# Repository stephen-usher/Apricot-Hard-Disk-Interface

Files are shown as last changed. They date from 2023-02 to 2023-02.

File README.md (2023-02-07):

# Apricot-Hard-Disk-Interface
 This is a board for the ACT Apricot series of computers providing virtual hard disks held on a FAT format microSD card.

 The core of this is a Raspberry Pi Pico which pretends to be most of the circuity on the original "Winchester Card", i.e. the WD1010-05 MFM hard disk controller chip, the 8K transfer static RAM and the  control latch. The main address translation is done via the two GALs and data/addresses and voltage levels are managed via the 74LS and 74AHCT chips controlled by the GALs.

 The board can be built in two forms. The first is fully populated and is a stand-alone unit which just plugs into the Apricot expansion bus connector. The second form is as a daughter board to my RAM  expansion card (which needs one bodge wire added to bring the ALE signal to the expansion connector) in which case it only requires the two 74AHCT chips and one GAL as all the other functionality is  provided by the RAM card.

 The source and binaries for the GAL code can be found in the GAL sub-directory.

 The Raspberry Pi Pico's software is written in C using the Pico SDK. I used the version which runs on a Raspberry Pi 4 to develop this. One core is used for the host interface and the other for the less  time critical parts such as emulating the WD1010-05 commands and talking to the microSD card.

 The microSD card interface I used was easily found on Amazon and targetted at the Arduino, hence why it is a 5V model. It's an "AZ-Delivery SPI Reader Micro". Others will probably work but the pin-outs may  be different.

 The PCB was designed using KiCAD 6.

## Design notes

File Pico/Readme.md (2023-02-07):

# The Raspberry Pi Pico code.
 The three directories here hold the source and binary files of the firmware for the Pico along with a dirctory with some sample hard disk images.

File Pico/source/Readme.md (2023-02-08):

# Raspberry Pi Pico firmware source.
 This source includes a copy of the ["no-OS-FatFS-SD-SPI-RPi-Pico" code by "carlk"](https://github.com/carlk3/no-OS-FatFS-SD-SPI-RPi-Pico), so as to access the micoSD card via SPI. This in turn has a copy of  [ChaN's FatFs - Generic FAT Filesystem Module.](http://elm-chan.org/fsw/ff/00index_e.html).

 The architecture is quite simple. The system first sets up the pins on the Pico, initialises the SD card interface, reads the config file and sets up the configuration for the virtual hard drives. It then  runs the host interface code on core 1 whilst core 0 waits for WD1010-05 commands and actions them.

 The buffer and many variables are shareed between the two cores, the variables being defined as volatile so that the compiler knows not to optimise accesses away or cache the values. This acts as the inter  core communication.

 Currently the only outstanding issue is that format.exe and the Activity Disk Tools format both hang when doing the low-level format. Actually, the programs both do a seek command, check the status register once after it's completed and then just sit there. There's no further interaction from the host. I've tried all potentially valid status register values and it makes no difference.

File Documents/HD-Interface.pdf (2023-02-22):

# !Electronic Svstem

1. Outline Of Controller.
2. Integrated Circuit Catalogue
3. Mnemonics

### 1. Outline of Controller

Introduction
The Winchester disk drive controller is a single board expansion card which fits into either one of the system expansion slots and connected to the disk drive by a ribbon cable.
The board acts as the interface between the processing system and the Winchester disk drive.

Description
The controller is broken into seven parts; the WD 1010-05, Data seperator, write precompesation, addressing, RAM buffer control port and finally a data bus.

Winchester Disk Controller (WD1010-05)
The Winchester disk interface consists of a WD 1 0 1 0-05 and associated buffers.
The interface provides all the control functions necessary for formatting and transferring data to and from the winchester disk.

Winchester 9

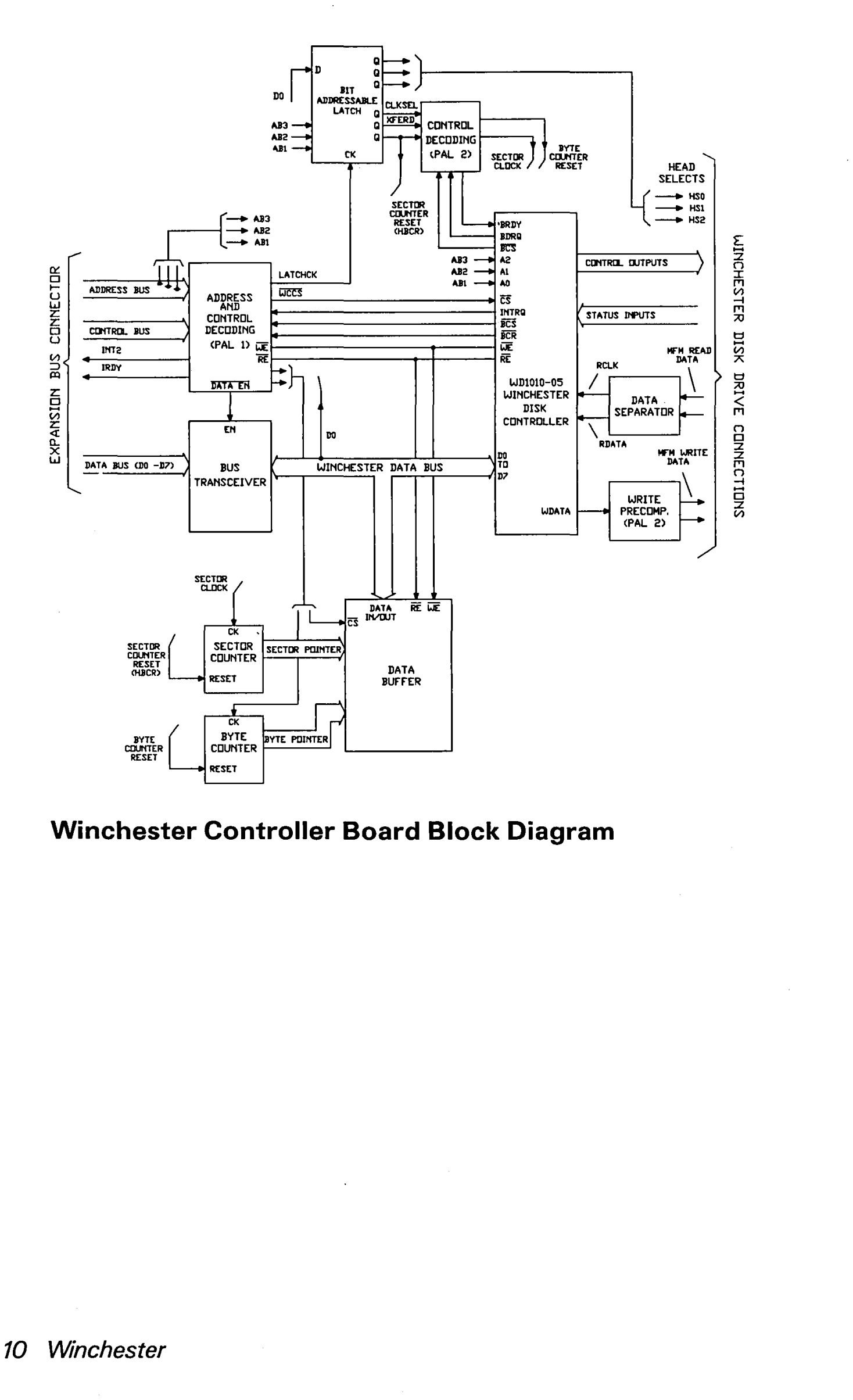
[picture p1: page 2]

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
'" ::::>

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
J:j_A113 _A112
_AlII

ADIlRt:SS BUS

ClJiTR!I.. BUS

ItfT2

DATA BUS (DO -D7)

SECTOR
CIlUIiTER
RESET
CHBCR)

BVTE CDUlfTER
RESET

ADDRESS AND

CONTROL
DECODING

EN

BUS
TRANSCEIVER

DO

A113

BYTE ClUfTER
RESET | HEAD

RE

WDIOIO-OS
WINCHESTER
DISK
CONTROLLER
DO

WINCHESTER DATA BUS ,-.-,-----{ID7

WDATA

SELECTS

_IiSO
_1iS1
_HS2

Winchester Controller Board Block Diagram

### 10 Winchester

£
2
n
I
rTJ
'" ⁻⁻I

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
The WD 1010-05 is selected by WCCS from PAL 1 . Head select is controlled by the control port (IC8).
The controllers registers are selected by AB 1 - 3 from the Apricot.

Data Separator.
The DP8460 (lC2) data separator receives digital pulses from a differential line receiver which converts the data from balanced to TTL format. The data separators lock to the frequency of these input pulses and separates them into synchronized data and clock signals.

Write Precompensation
The Rodime R0350 does not require write precompensation although the controller is capable of producing early, normal and late data. Write data (WDATA) from the WD 1010-05 can be used to drive a delay line, (Not normally fitted). This generates two extra write data signals delayed by 1 Ons and 20ns. These data signals are then selected by PAL2 which is controlled by RWC/EARLY and LATE from the WD1010-05. The write data output of PAL2 is converted to balanced format by the differential line drive.

Addressing.
The PAL 1 is used to interface the address bus from the Apricot to the Winchester controller. It receives address lines AB4-AB8 which allows the controller to detect accesses to the WD1010-05.
The control port and the data port ABO qualifies the device selects and ALE is used to prevent glitches as the addresses change.
When the WD 1010-05 isolates the local bus to perform a data transfer the PAL 1 would produce NRAMCS from the appropriate address. PAL 1 is also enabled by BCS from the WD1010-05.
The WD 1010-05 interrupt request output (INTRQ) is bufferd by PAL 1 and output as NINT2 to the Apricot.
To meet the address setup times of the WD 10 10-05, the read enable signal is delayed by qualifying it with the data enable signal whenever the controller is addressed by the Apricot Ica also adds additional wait states by holding IRDY low until its Qc output goes high. This counter is clocked by the 5MHz clock (CLK5).

The expansion bus is buffered by tri-state drivers to avoid contention with other expansion cards.

Control Port
The control port (IC6) is an 8 bit addressable latch enabled by the signallatch-CK from PAL 1.
The signals HSO-HS2 are used to select the winchester head. ClKSEl defines if the system processor or the WD 1 0 1 0-05 causes the sector pointer to be incremented.
XFERD is a handshaking protocol informing the
WD 1010-05 that data is available.
HBCR is used to reset both the sector pointer and the byte pointer to zero. It is controlled by the system processor.

Data Bus
The local data bus is isolated from the expansion bus by IC5 an octal bus transceiver. Its"direction is controlled by NIORC from the Apricot and enabled by NDATAEN from PAL 1.

Static Ram.
This 8K x 8 or 2K x 8 bit buffer acts as a temporary store for all data transfers. Data is written into the buffer from the Apricot and then access is passed to the WD 1010-05 which transferes the data to the winchester disk.
RAM chip select, read enable and write enable are controlled by PAL 1.
The RAM addresses are generated by counters which form the byte pointer( IC7 + IC 1 O} and sector pointer{lC8}.

The byte counter is incremented by the byte clock from
PAL 1 and goes high whenever RE or WE is active from either the CPU or WD10105.
The sector counter is clocked by sector ClK from PAl2. This is derived from either the Byte counter reaching its
maximum count or from the buffer data request of the WD1010-05.
The byte counter is reset by the signal BCR from IC4. This is generated by either the system {HBCR} or the WD 1 01 0-05 (NWBCR).
The sector counter is only reset by the system {HBCR}, this is to allow for a WD 1010-05 option to be implemented.

12 Winchester

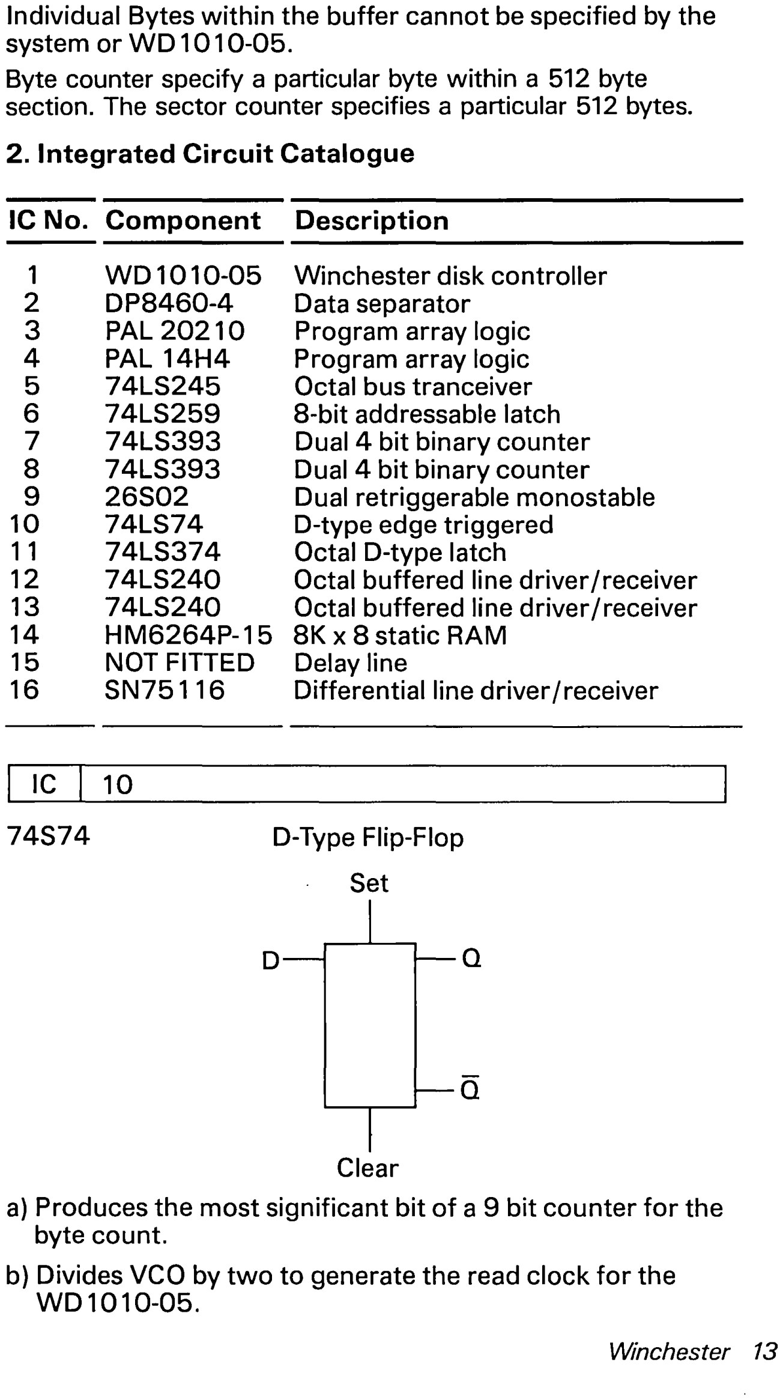
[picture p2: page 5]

Individual Bytes within the buffer cannot be specified by the system or WD 1 0 1 0-05.
Byte counter specify a particular byte within a 512 byte section. The sector counter specifies a particular 512 bytes.
2. Integrated Circuit Catalogue

IC No. Component Description

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
WD1010-05
DP8460-4
PAL 20210
PAL 14H4
74LS245
74LS259
74LS393
74LS393
26S02
74LS74
74LS374
74LS240
74LS240
HM6264P-15
NOT FITTED
SN75116

IC 10

Winchester disk controller Data separator
Program array logic
Program array logic
Octal bus tranceiver
8-bit addressable latch
Dual 4 bit binary counter
Dual 4 bit binary counter
Dual retriggerable monostable D-type edge triggered
Octal D-type latch
Octal buffered line driver/receiver Octal buffered line driver/receiver 8K x 8 static RAM
Delay line
Differential line driver/receiver
74S74 | D-Type Flip-Flop

Set

D | Q

0:

Clear
a) Produces the most significant bit of a 9 bit counter for the byte count.
b) Divides VCO by two to generate the read clock for the WD1010-05.

IC | 11
74LS374 | Octal D-Type Flip Flop.
D | Q

Clk----f

D/P Enable

Latches write data and precompensation outputs from the Write data and precompensation outputs from the Winchester controller. It also latches write clock and buffer data request.

I IC I 12, 13

74LS240 Octal Buffer Line Driver/Receiver
IC 12 Seven buffers are used to buffer controller signals to the Winchester disk drive. The remaining buffer is used as an input to a 4 bit binary counter for the sector clock.
IC 13. Buffers used to buffer Winchester controller signals from the Winchester disk drive.

I IC I 7,8

74LS393 | 4 Bit Binary Counter

IC 7 dual 4 bit counter used to produce 8 bits of a 9 bit byte counter.
IC8 One counter used for the sector counter and the second allows for the addition of extra wait states.

14 Winchester

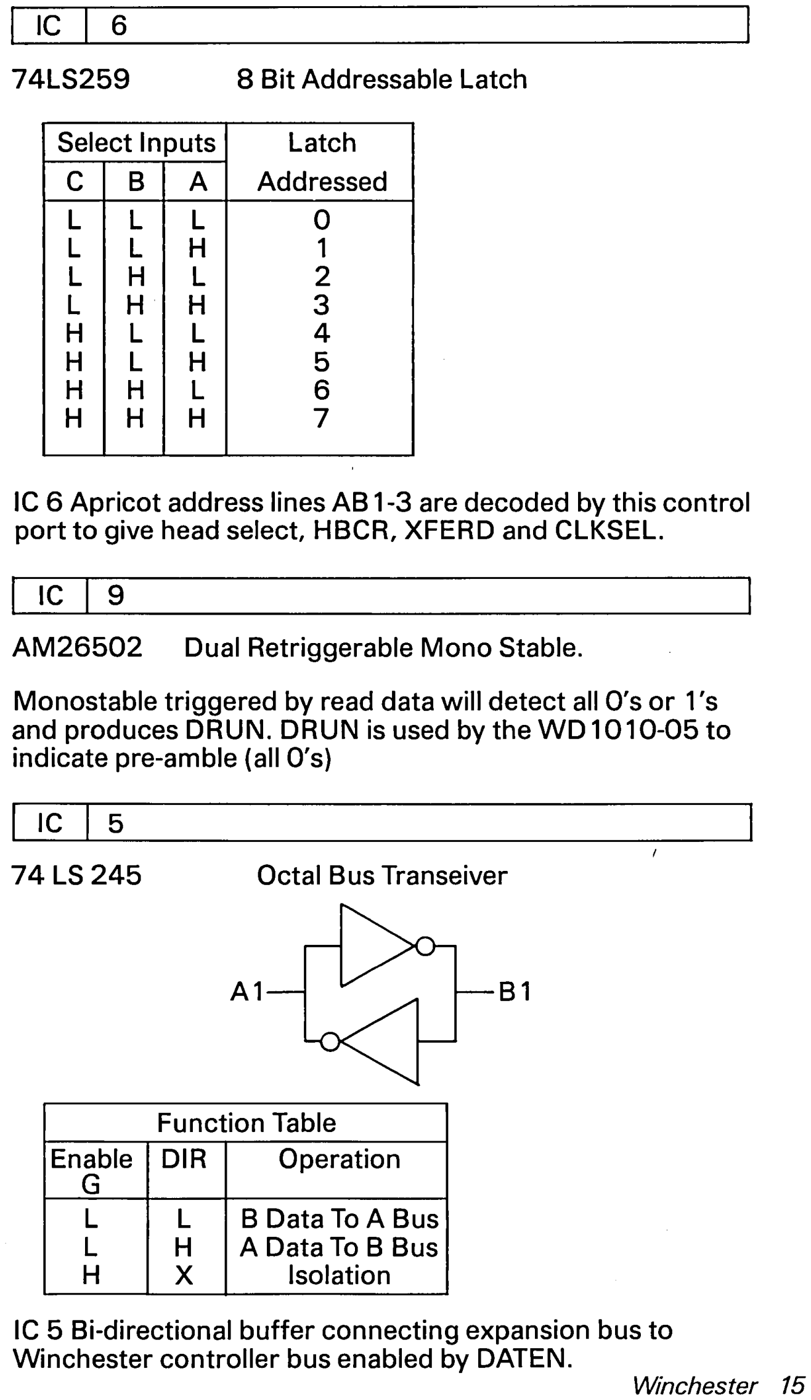
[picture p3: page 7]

Ie | 6
74LS259 | 8 Bit Addressable Latch
Select Inputs | Latch Addressed
C | B | A
L L L L H H H H | L L H H L L H H | L H L H L H L H | 0 1 2 3 4 5 6 7

IC 6 Apricot address lines AB 1-3 are decoded by this control port to give head select, HBCR, XFERD and CLKSEL.

I IC 19

AM26502 Dual Retriggerable Mono Stable.

Monostable triggered by read data will detect all O's or 1 's and produces DRUN. DRUN is used by the WD 1010-05 to indicate pre-amble (all O's)

# I IC I 5

74 LS 245 | Octal Bus Transeiver
A1 | B1

Function Table
Enable G | DIR | Operation
L L H | L H X | B Data To A Bus A Data To B Bus Isolation

IC 5 Bi-directional buffer connecting expansion bus to Winchester controller bus enabled by DATEN.

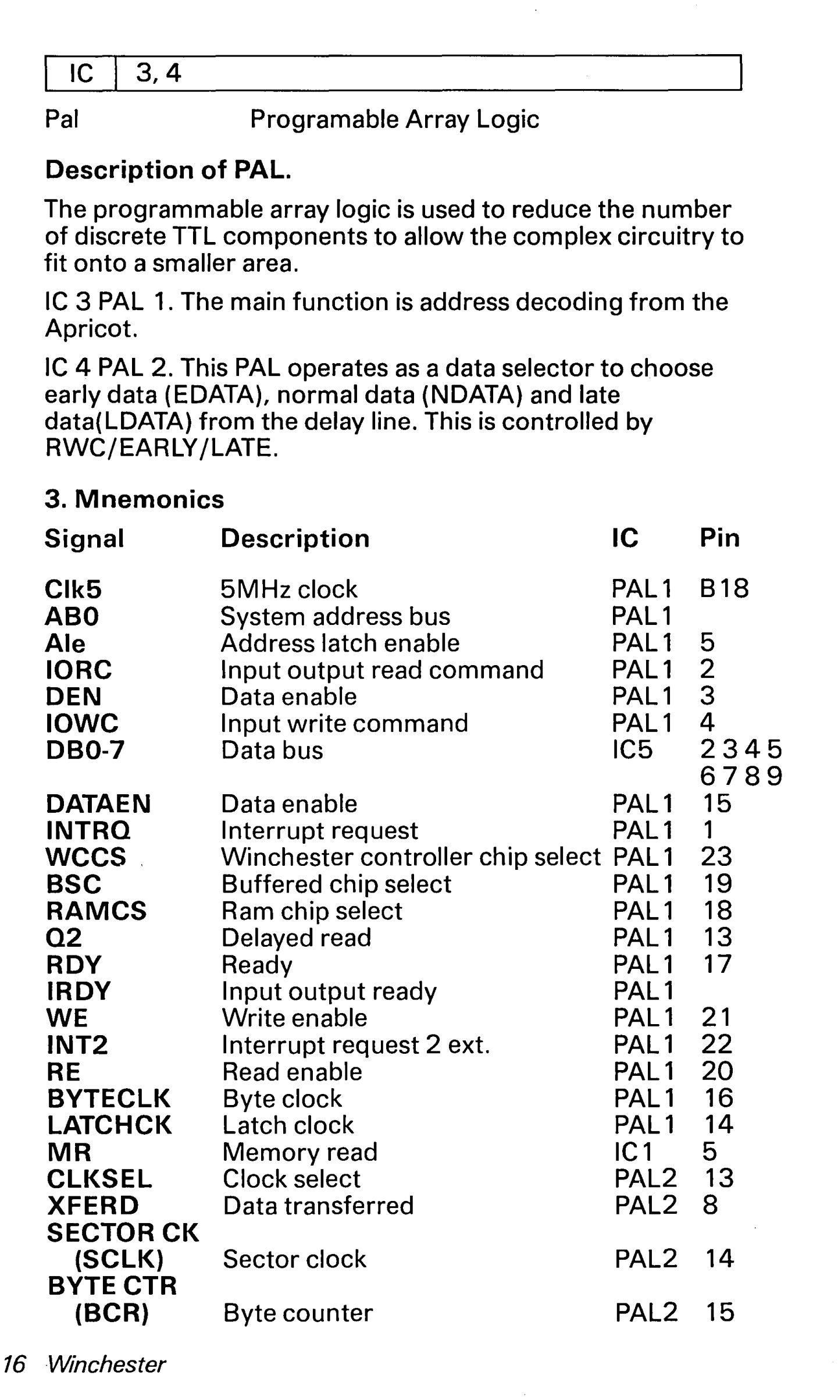
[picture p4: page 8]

16

IC | 3,4
Pal | Programable Array Logic

Description of PAL.
The programmable array logic is used to reduce the number of discrete TTL components to allow the complex circuitry to fit onto a smaller area.
IC 3 PAL 1. The main function is address decoding from the Apricot.
IC 4 PAL 2. This PAL operates as a data selector to choose early data (EDATA), normal data (NDATA) and late
data( LDATA) from the delay line. This is controlled by RWC/EARLY /LATE.
3. Mnemonics
Signal | Description | IC
Clk5 | 5MHz clock | PAL1
ABO | System address bus | PAL 1
Ale | Address latch enable | PAL1
IORC | Input output read command | PAL1
DEN | Data enable | PAL1
IOWC | Input write command | PAL 1
DBO-7 | Data bus | IC5
DATAEN | Data enable | PAL1
INTRO | Interrupt request | PAL 1
WCCS. | Winchester controller chip select PAL 1
BSC | Buffered chip select | PAL1
RAMCS | Ram chip select | PAL1
02 | Delayed read | PAL1
RDY | Ready | PAL1
IRDY | Input output ready | PAL1
WE | Write enable | PAL 1
INT2 | Interrupt request 2 ext. | PAL 1
RE | Read enable | PAL1
BYTECLK | Byte clock | PAL 1
LATCHCK | Latch clock | PAL1
MR | Memory read | le1
CLKSEL | Clock select | PAL2
XFERD | Data transferred | PAL2
SECTOR CK
(SCLK) | Sector clock | PAL2
BYTE CTR
(BCR) | Byte counter | PAL2

Winchester

Pin

B18

5
2
3
4
2345
6789
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
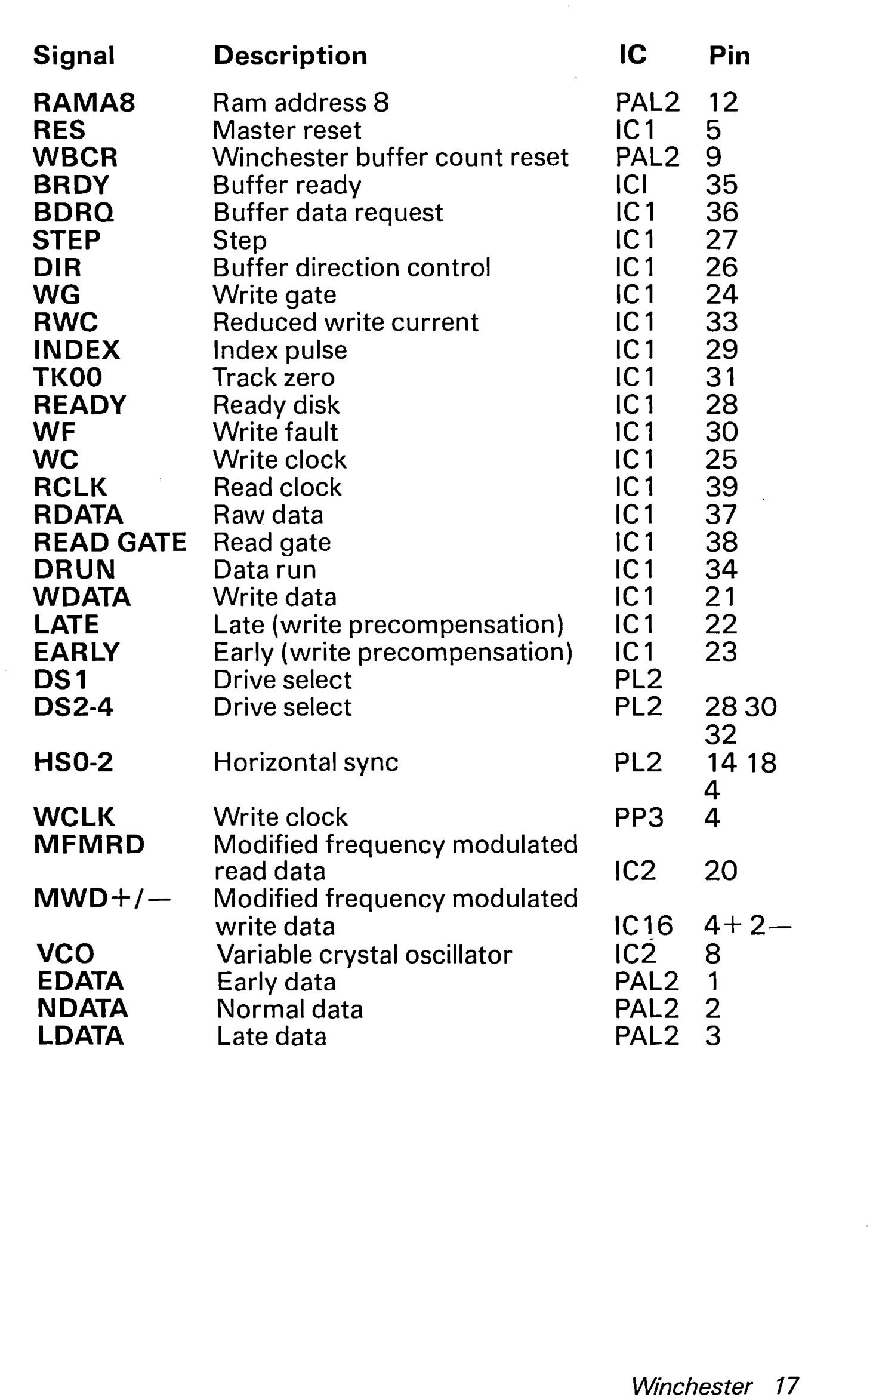
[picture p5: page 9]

Signal | Description | IC | Pin
RAMA8 | Ram address 8 | PAL2 12
RES | Master reset | IC 1 | 5
WBCR | Winchester buffer count reset | PAL2 9
BRDY | Buffer ready | ICI | 35
BDRQ | Buffer data request | IC 1 | 36
STEP | Step | IC1 | 27
DIR | Buffer direction control | IC1 | 26
WG | Write gate | IC1 | 24
RWC | Reduced write current | IC1 | 33
INDEX | Index pulse | IC1 | 29
TKOO | Track zero | IC1 | 31
READY | Ready disk | IC1 | 28
WF | Write fault | IC1 | 30
WC | Write clock | IC1 | 25
RCLK | Read clock | IC1 | 39
RDATA | Raw data | IC1 | 37
READ GATE Read gate | IC1 | 38
DRUN | Data run | IC1 | 34
WDATA | Write data | IC 1 | 21
LATE | Late (write precompensation) | IC1 | 22
EARLY | Early (write precompensation) | IC 1 | 23
DS1 | Drive select | PL2
DS2-4 | Drive select | PL2 | 2830
| | | 32
HSO-2 | Horizontal sync | PL2 | 14 18
| | | 4
WCLK | Write clock | PP3 | 4
MFMRD | Modified frequency modulated
| read data | IC2 | 20
MWD+/- | Modified frequency modulated
| write data | IC16 | 4+2-
VCO | Variable crystal oscillator | IC2 | 8
EDATA | Early data | PAL2 1
NDATA | Normal data | PAL2 2
LDATA | Late data | PAL2 3

# Parts list

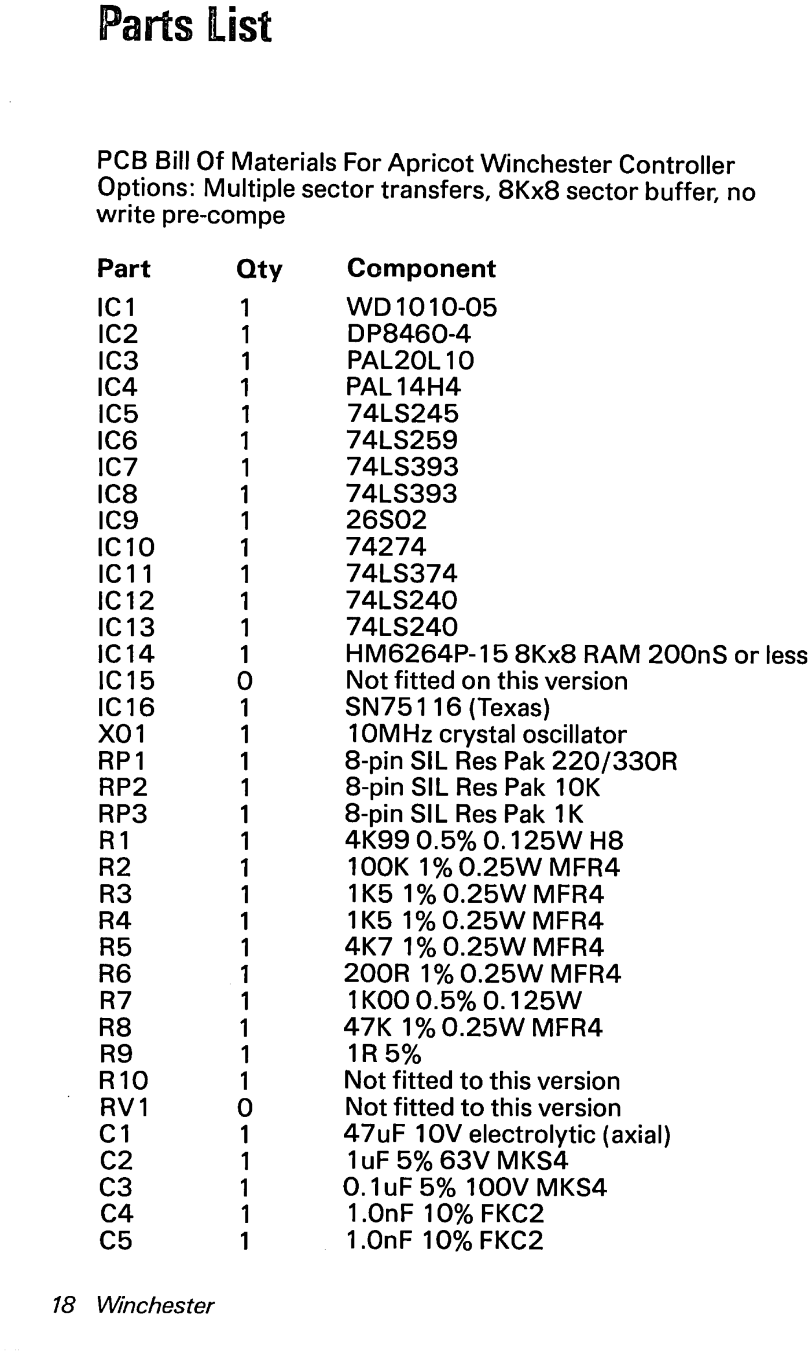
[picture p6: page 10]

PCB Bill Of Materials For Apricot Winchester Controller Options: Multiple sector transfers, 8Kx8 sector buffer, no write pre-compe

Part
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
IC10
IC 11
IC12
IC13
IC14
IC15
IC16
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
18 Winchester

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
Component
WD1010-05
DP8460-4
PAL20L10
PAL 14H4
74LS245
74LS259
74LS393
74LS393
26S02
74274
74LS374
74LS240
74LS240
HM6264P-15 8Kx8 RAM 200nS or less Not fitted on this version
SN75116 (Texas)
10M Hz crystal oscillator
8-pin SIL Res Pak 220/330R 8-pin SIL Res Pak 10K
8-pin SIL Res Pak 1 K
4K99 0.5% O. 125W H8
100K 1 % 0.25W MFR4
1 K5 1 % 0.25W MFR4
1 K5 1 % 0.25W MFR4
4K7 1% 0.25W MFR4
200R 1 % 0.25W MFR4
1 KOO 0.5% O. 125W
47K 1 % 0.25W MFR4
1R5%
Not fitted to this version Not fitted to this version 47uF 10V electrolytic (axial) 1 uF 5% 63V MKS4
O. 1 uF 5% 100V MKS4
1.0nF 10% FKC2
1.0nF 10% FKC2

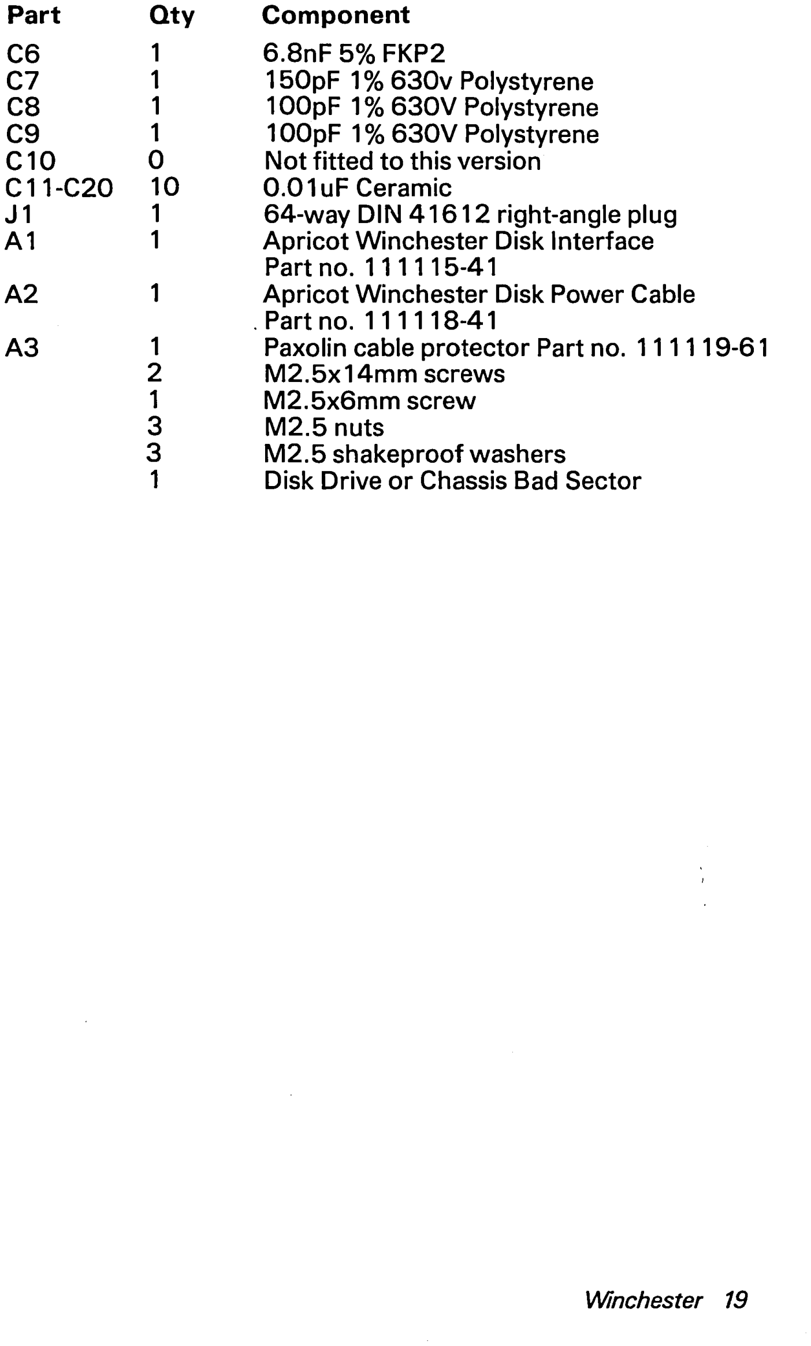
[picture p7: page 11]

Part | Qty
C6 | 1
C7 | 1
C8 | 1
C9 | 1
C10 | 0
C11-C20 | 10
J 1 | 1
A 1 | 1

A2

A3 | 1
2
| 1
3
| 3
| 1

Component
6.8nF 5% FKP2
150pF 1 % 630v Polystyrene 100pF 1 % 630V Polystyrene 100pF 1 % 630V Polystyrene
Not fitted to this version
0.01 uF Ceramic
64-way DIN 41612 right-angle plug Apricot Winchester Disk Interface Part no. 111115-41
Apricot Winchester Disk Power Cable
. Part no. 111118-41
Paxolin cable protector Part no. 111119-61 M2.5x 14mm screws
M2.5x6mm screw
M2.5 nuts
M2.5 shakeproof washers
Disk Drive or Chassis Bad Sector

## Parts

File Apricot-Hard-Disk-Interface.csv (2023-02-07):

Source: | Z:\Data\Kicad\Apricot-Hard-Disk-Interface\Apricot-Hard-Disk-Interface.kicad_sch
Date: | 18/12/2022 07:52:19
Tool: | Eeschema (6.0.9)
Generator: | C:\Program Files\KiCad\6.0\bin\scripting\plugins/bom_csv_grouped_by_value_with_fp.py
Component Count: | 21
Ref | Qnty | Value | Cmp name | Footprint | Description | Vendor
C1, C2, C3, C4, C5, C6, C7, | 7 | 1uF | C | Capacitor_SMD:C_0805_2012Metric | Unpolarized capacitor
D1, | 1 | 1N4001 | 1N4001 | Diode_THT:D_DO-41_SOD81_P10.16mm_Horizontal | 50V 1A General Purpose Rectifier Diode, DO-41
J1, | 1 | Motherboard Connector | Conn_02x32_Row_Letter_First | Connector_DIN:DIN41612_B_2x32_Male_Horizontal_THT | Generic connector, double row, 02x32, row letter first pin numbering scheme (pin number consists of a letter for the row and a number for the pin index in this row. a1, ..., aN; b1, ..., bN), script generated (kicad-library-utils/schlib/autogen/connector/)
J2, | 1 | Expansion | Conn_02x32_Row_Letter_First | Connector_DIN:DIN41612_B_2x32_Female_Vertical_THT | Generic connector, double row, 02x32, row letter first pin numbering scheme (pin number consists of a letter for the row and a number for the pin index in this row. a1, ..., aN; b1, ..., bN), script generated (kicad-library-utils/schlib/autogen/connector/)
J3, | 1 | SD_CARD_READER | Conn_01x06_Female | Connector_PinSocket_2.54mm:PinSocket_1x06_P2.54mm_Horizontal | Generic connector, single row, 01x06, script generated (kicad-library-utils/schlib/autogen/connector/)
P1, | 1 | Pico | Pico | MCU_RaspberryPi_and_Boards:RPi_Pico_SMD_TH
RN1, RN2, | 2 | 10K | R_Network08 | Resistor_THT:R_Array_SIP9 | 8 resistor network, star topology, bussed resistors, small symbol
U1, U4, | 2 | GAL16V8 | GAL16V8 | Package_DIP:DIP-20_W7.62mm_Socket | Programmable Logic Array, DIP-20/SOIC-20/PLCC-20
U2, | 1 | 74AHCT244 | 74AHCT244 | Package_DIP:DIP-20_W7.62mm_Socket | 8-bit Buffer/Line Driver 3-state
U3, U5, | 2 | 74LS245 | 74LS245 | Package_DIP:DIP-20_W7.62mm_Socket | Octal BUS Transceivers, 3-State outputs
U6, U7, | 2 | 74LS373 | 74LS373 | Package_DIP:DIP-20_W7.62mm_Socket | 8-bit Latch, 3-state outputs

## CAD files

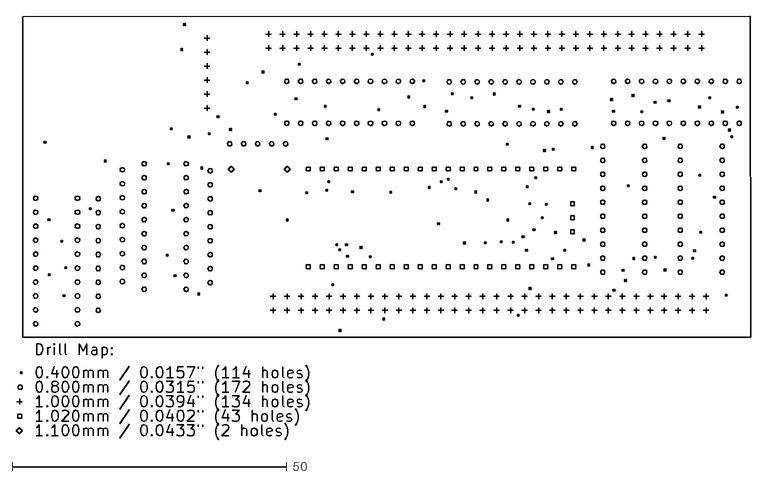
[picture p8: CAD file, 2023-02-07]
Gerber/Apricot-Hard-Disk-Interface-PTH-drl_map.dxf
133.6 x 77.1

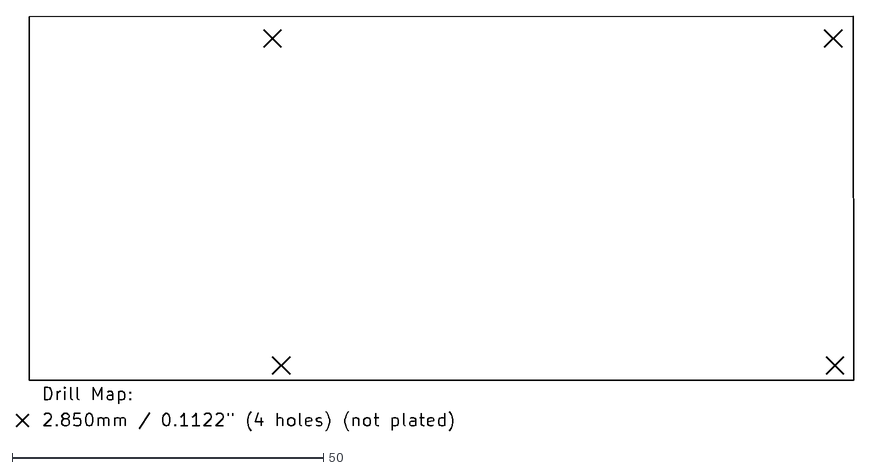
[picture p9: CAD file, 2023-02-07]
Gerber/Apricot-Hard-Disk-Interface-NPTH-drl_map.dxf
134.4 x 66.5

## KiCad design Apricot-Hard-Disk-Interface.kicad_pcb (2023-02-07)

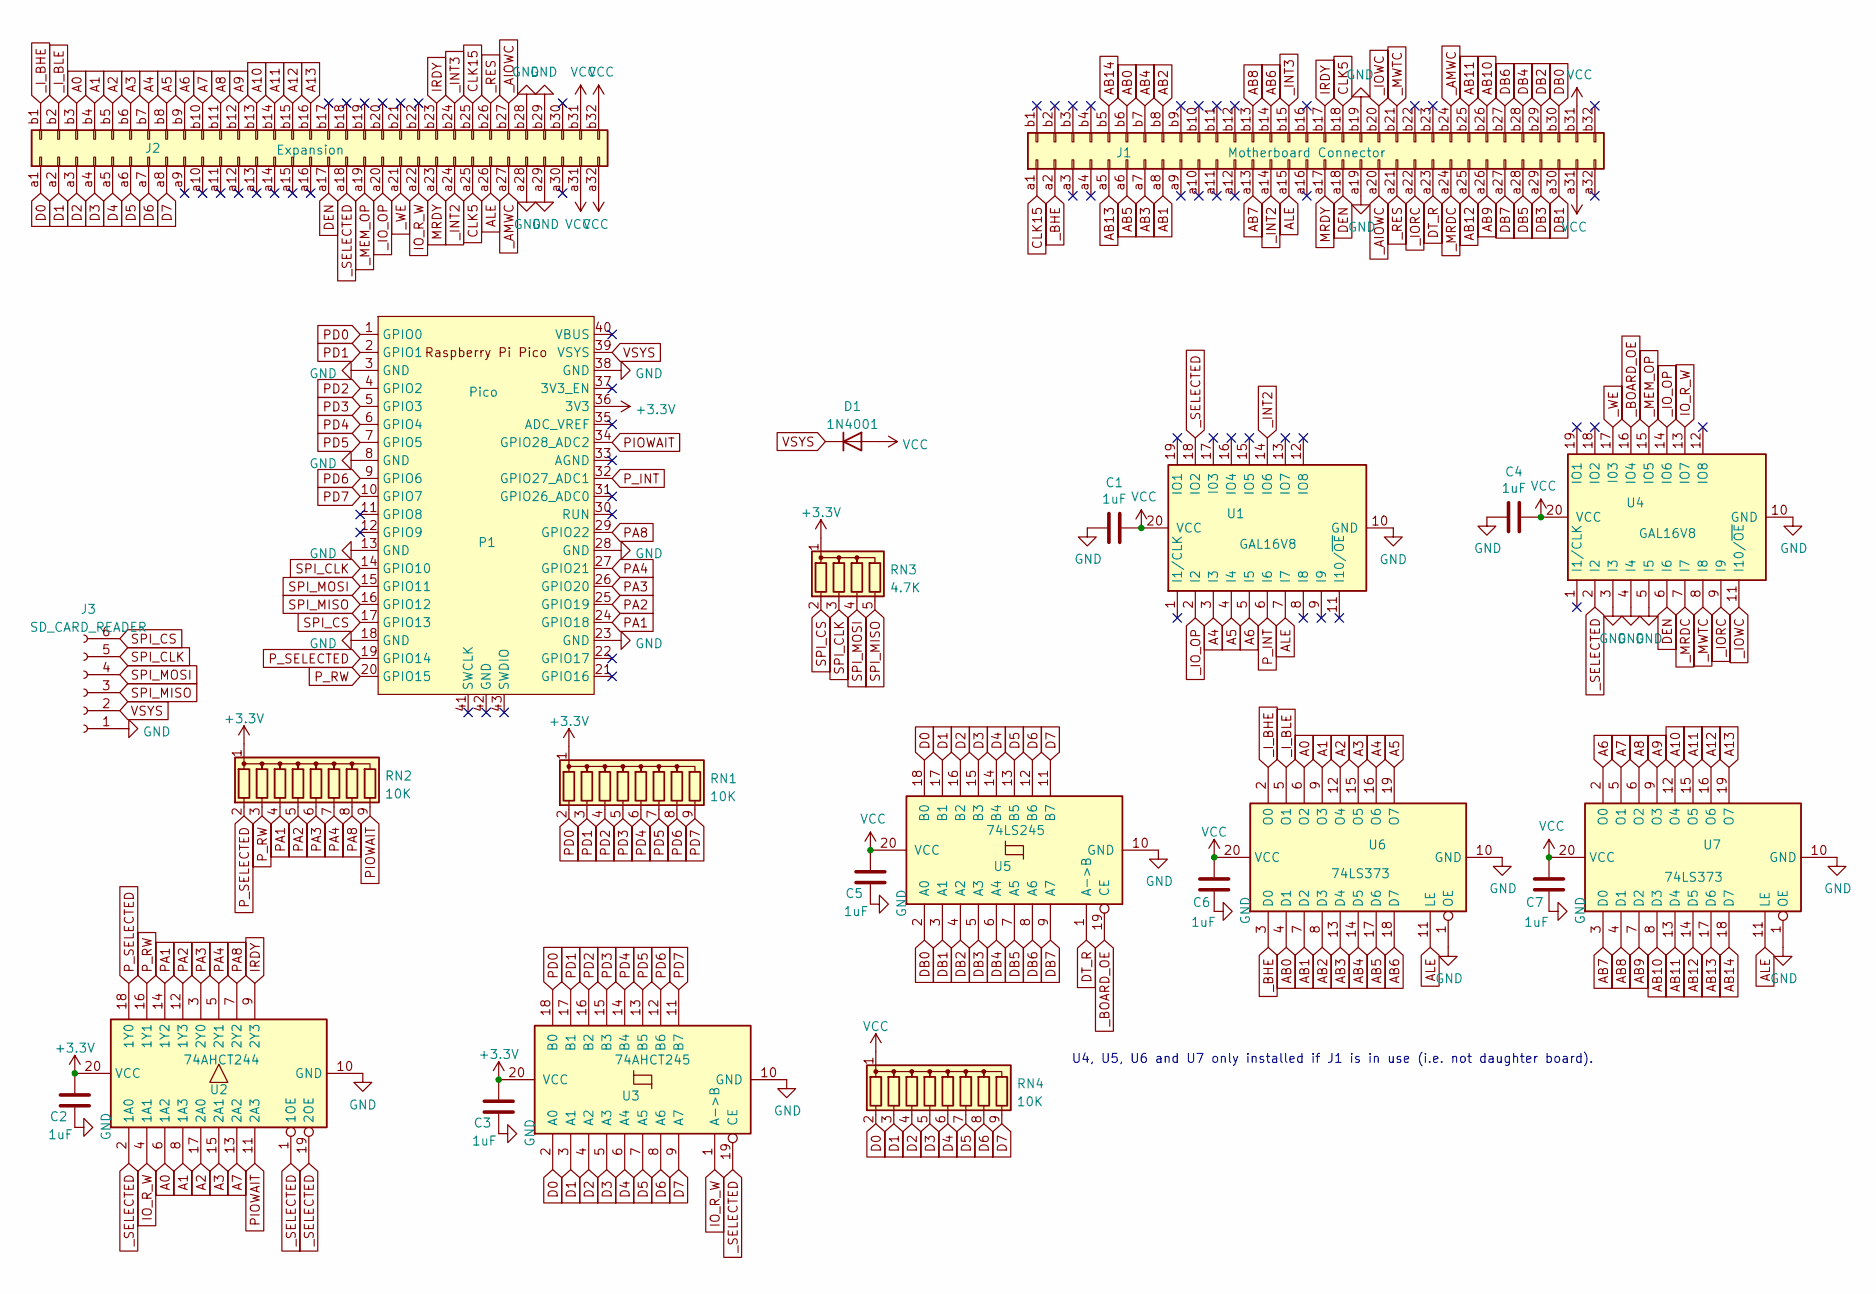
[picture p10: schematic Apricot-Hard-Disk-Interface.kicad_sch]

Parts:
C1, C2, C3, C4, C5, C6, C7: 1uF; C_0805_2012Metric
D1: 1N4001; D_DO-41_SOD81_P10.16mm_Horizontal
J1: Motherboard Connector; DIN41612_B_2x32_Male_Horizontal_THT
J2: Expansion; DIN41612_B_2x32_Female_Vertical_THT
J3: SD_CARD_READER; PinSocket_1x06_P2.54mm_Horizontal
P1: Pico; RPi_Pico_SMD_TH
RN1, RN2, RN4: 10K; R_Array_SIP9
RN3: 4.7K; R_Array_SIP5
U1, U4: GAL16V8; DIP-20_W7.62mm_Socket
U2: 74AHCT244; DIP-20_W7.62mm_Socket
U3: 74AHCT245; DIP-20_W7.62mm_Socket
U5: 74LS245; DIP-20_W7.62mm_Socket
U6, U7: 74LS373; DIP-20_W7.62mm_Socket

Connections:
+3.3V: C2.1, C3.1, P1.36 (3V3), RN1.1 (common), RN2.1 (common), RN3.1 (common), U2.20 (VCC), U3.20 (VCC)
A0: J2.b3, U2.6 (1A2), U6.6 (O2)
A1: J2.b4, U2.8 (1A3), U6.9 (O3)
A2: J2.b5, U2.17 (2A0), U6.12 (O4)
A3: J2.b6, U2.15 (2A1), U6.15 (O5)
A4: J2.b7, U1.3 (I3), U6.16 (O6)
A5: J2.b8, U1.4 (I4), U6.19 (O7)
A6: J2.b9, U1.5 (I5), U7.2 (O0)
A7: J2.b10, U2.13 (2A2), U7.5 (O1)
A8: J2.b11, U7.6 (O2)
A9: J2.b12, U7.9 (O3)
A10: J2.b13, U7.12 (O4)
A11: J2.b14, U7.15 (O5)
A12: J2.b15, U7.16 (O6)
A13: J2.b16, U7.19 (O7)
AB0: J1.b6, U6.4 (D1)
AB1: J1.a8, U6.7 (D2)
AB2: J1.b8, U6.8 (D3)
AB3: J1.a7, U6.13 (D4)
AB4: J1.b7, U6.14 (D5)
AB5: J1.a6, U6.17 (D6)
AB6: J1.b14, U6.18 (D7)
AB7: J1.a13, U7.3 (D0)
AB8: J1.b13, U7.4 (D1)
AB9: J1.a26, U7.7 (D2)
AB10: J1.b26, U7.8 (D3)
AB11: J1.b25, U7.13 (D4)
AB12: J1.a25, U7.14 (D5)
AB13: J1.a5, U7.17 (D6)
AB14: J1.b5, U7.18 (D7)
ALE: J1.a15, J2.a26, U1.7 (I7), U6.11 (LE), U7.11 (LE)
CLK5: J1.b18, J2.a25
CLK15: J1.a1, J2.b25
D0: J2.a1, RN4.2 (R1), U3.2 (A0), U5.18 (B0)
D1: J2.a2, RN4.3 (R2), U3.3 (A1), U5.17 (B1)
D2: J2.a3, RN4.4 (R3), U3.4 (A2), U5.16 (B2)
D3: J2.a4, RN4.5 (R4), U3.5 (A3), U5.15 (B3)
D4: J2.a5, RN4.6 (R5), U3.6 (A4), U5.14 (B4)
D5: J2.a6, RN4.7 (R6), U3.7 (A5), U5.13 (B5)
D6: J2.a7, RN4.8 (R7), U3.8 (A6), U5.12 (B6)
D7: J2.a8, RN4.9 (R8), U3.9 (A7), U5.11 (B7)
DB0: J1.b30, U5.2 (A0)
DB1: J1.a30, U5.3 (A1)
DB2: J1.b29, U5.4 (A2)
DB3: J1.a29, U5.5 (A3)
DB4: J1.b28, U5.6 (A4)
DB5: J1.a28, U5.7 (A5)
DB6: J1.b27, U5.8 (A6)
DB7: J1.a27, U5.9 (A7)
DEN: J1.a18, J2.a17, U4.6 (I6)
DT_R: J1.a23, U5.1 (A->B)
GND: C1.2, C2.2, C3.2, C4.2, C5.2, C6.2, C7.2, J1.a19, J1.b19, J2.a28, J2.a29, J2.b28, J2.b29, J3.1, P1.3 (GND), P1.8 (GND), P1.13 (GND), P1.18 (GND), P1.23 (GND), P1.28 (GND), P1.38 (GND), U1.10 (GND), U2.10 (GND), U3.10 (GND), U4.3 (I3), U4.4 (I4), U4.5 (I5), U4.10 (GND), U5.10 (GND), U6.1 (OE), U6.10 (GND), U7.1 (OE), U7.10 (GND)
IO_R_W: J2.a22, U2.4 (1A1), U3.1 (A->B), U4.13 (IO7)
IRDY: J1.b17, J2.b23, U2.9 (2Y3)
MRDY: J1.a17, J2.a23
PA1: P1.24 (GPIO18), RN2.4 (R3), U2.14 (1Y2)
PA2: P1.25 (GPIO19), RN2.5 (R4), U2.12 (1Y3)
PA3: P1.26 (GPIO20), RN2.6 (R5), U2.3 (2Y0)
PA4: P1.27 (GPIO21), RN2.7 (R6), U2.5 (2Y1)
PA8: P1.29 (GPIO22), RN2.8 (R7), U2.7 (2Y2)
PD0: P1.1 (GPIO0), RN1.2 (R1), U3.18 (B0)
PD1: P1.2 (GPIO1), RN1.3 (R2), U3.17 (B1)
PD2: P1.4 (GPIO2), RN1.4 (R3), U3.16 (B2)
PD3: P1.5 (GPIO3), RN1.5 (R4), U3.15 (B3)
PD4: P1.6 (GPIO4), RN1.6 (R5), U3.14 (B4)
PD5: P1.7 (GPIO5), RN1.7 (R6), U3.13 (B5)
PD6: P1.9 (GPIO6), RN1.8 (R7), U3.12 (B6)
PD7: P1.10 (GPIO7), RN1.9 (R8), U3.11 (B7)
PIOWAIT: P1.34 (GPIO28_ADC2), RN2.9 (R8), U2.11 (2A3)
P_INT: P1.32 (GPIO27_ADC1), U1.6 (I6)
P_RW: P1.20 (GPIO15), RN2.3 (R2), U2.16 (1Y1)
P_SELECTED: P1.19 (GPIO14), RN2.2 (R1), U2.18 (1Y0)
SPI_CLK: J3.5, P1.14 (GPIO10), RN3.3 (R2)
SPI_CS: J3.6, P1.17 (GPIO13), RN3.2 (R1)
SPI_MISO: J3.3, P1.16 (GPIO12), RN3.5 (R4)
SPI_MOSI: J3.4, P1.15 (GPIO11), RN3.4 (R3)
VCC: C1.1, C4.1, C5.1, C6.1, C7.1, D1.2 (A), J1.a31, J1.b31, J2.a31, J2.a32, J2.b31, J2.b32, RN4.1 (common), U1.20 (VCC), U4.20 (VCC), U5.20 (VCC), U6.20 (VCC), U7.20 (VCC)
VSYS: D1.1 (K), J3.2, P1.39 (VSYS)
_AIOWC: J1.a20, J2.b27
_AMWC: J1.b24, J2.a27
_BHE: J1.a2, U6.3 (D0)
_BOARD_OE: U4.16 (IO4), U5.19 (CE)
_INT2: J1.a14, J2.a24, U1.14 (IO6)
_INT3: J1.b15, J2.b24
_IORC: J1.a22, U4.9 (I9)
_IOWC: J1.b20, U4.11 (I10/~OE)
_IO_OP: J2.a20, U1.2 (I2), U4.14 (IO6)
_I_BHE: J2.b1, U6.2 (O0)
_I_BLE: J2.b2, U6.5 (O1)
_MEM_OP: J2.a19, U4.15 (IO5)
_MRDC: J1.a24, U4.7 (I7)
_MWTC: J1.b21, U4.8 (I8)
_RES: J1.a21, J2.b26
_SELECTED: J2.a18, U1.18 (IO2), U2.1 (1OE), U2.2 (1A0), U2.19 (2OE), U3.19 (CE), U4.2 (I2)
_WE: J2.a21, U4.17 (I03)

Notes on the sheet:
U4, U5, U6 and U7 only installed if J1 is in use (i.e. not daughter board).

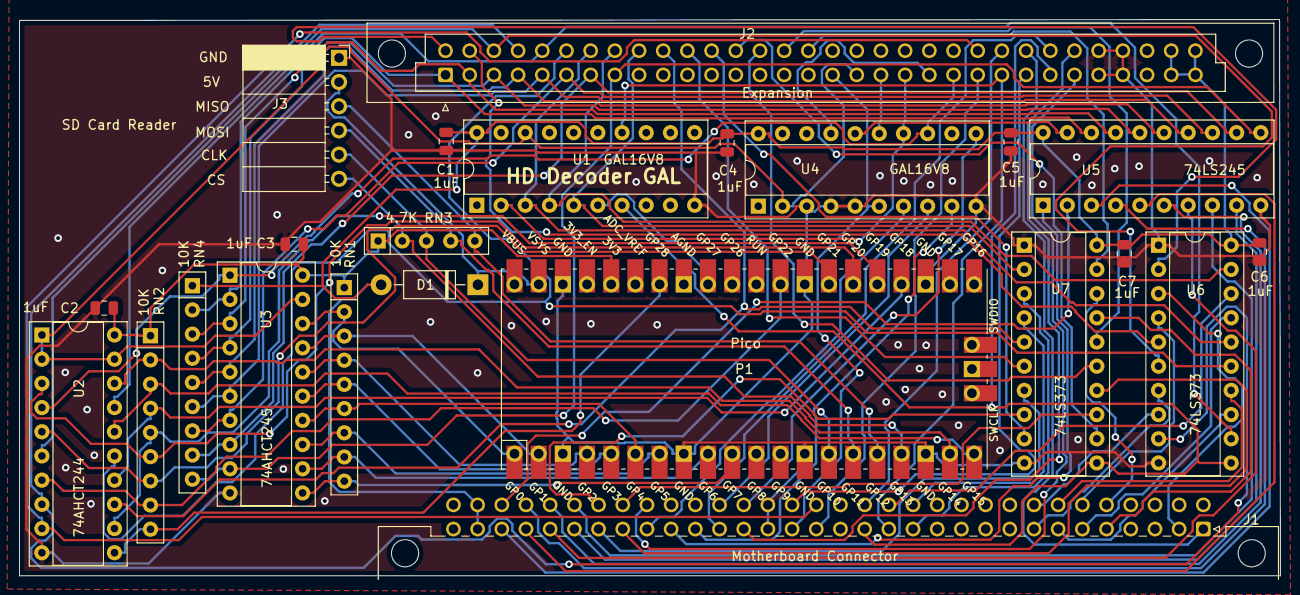
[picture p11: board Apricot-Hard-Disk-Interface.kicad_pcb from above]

Board: 2 copper layers, 132.4 x 58.4 mm, 23 parts (0 on the bottom side), 95 nets.

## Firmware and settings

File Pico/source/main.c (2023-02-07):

#include <stdio.h>
#include <stdlib.h>

#include "pico/stdlib.h"
#include "pico/multicore.h"
#include "hardware/rtc.h"
#include "hardware/adc.h"

#include "rtc.h"

#include "sd_stdio.h"
#include "apricot-hd.h"

sd_card_t *SD;

volatile unsigned char brdy, cmdrdy, dsk_errored;

volatile LATCH latch;
volatile unsigned char cur_drive, wd_cur_drive;

volatile WDREG host_reg_precomp, host_reg_sect_cnt, host_reg_sect_num;
volatile WDREG host_reg_cyl_low, host_reg_cyl_high, host_reg_sdh;
volatile WDREG wd_reg_errflg, wd_reg_sect_cnt, wd_reg_sect_num;
volatile WDREG wd_reg_cyl_low, wd_reg_cyl_high, wd_reg_sdh;
volatile WDCMD host_cmd;
volatile WDSTAT wd_reg_status;

CONFIG *hd_conf;

int flashcodes[6][5] = {
	{ 2, 1, 0, 0, 0},
	{ 3, 1, 0, 0, 0 },
	{ 4, 1, 0, 0, 0 },
	{ 4, 1, 1, 0, 0 },
	{ 4, 1, 1, 1, 0 },
	{ 4, 1, 1, 1, 1 }
};

#ifdef APRIDEBUG
void print_fileinfo(char *fname)
{
	FRESULT fr;
	FILINFO fno;

	fr = f_stat(fname, &fno);

	printf("Filename: %s\n", fname);

	switch (fr)
	{
		case FR_OK:
			printf("Size: %lu\n", fno.fsize);
			printf("Timestamp: %u-%02u-%02u, %02u:%02u\n",
			       (fno.fdate >> 9) + 1980, fno.fdate >> 5 & 15, fno.fdate & 31,
			       fno.ftime >> 11, fno.ftime >> 5 & 63);
			printf("Attributes: %c%c%c%c%c\n",
			       (fno.fattrib & AM_DIR) ? 'D' : '-',
			       (fno.fattrib & AM_RDO) ? 'R' : '-',
			       (fno.fattrib & AM_HID) ? 'H' : '-',
			       (fno.fattrib & AM_SYS) ? 'S' : '-',
			       (fno.fattrib & AM_ARC) ? 'A' : '-');
			break;
		case FR_NO_FILE:
			printf("\"%s\" does not exist.\n", fname);
			break;
		default:
			printf("An error occured. (%d)\n", fr);
	}		
}
#endif

int main()
{
	int i, j, create, written;
	size_t size;
	char buffer[1024], *ptr;
	char *filename;
	FRESULT retval;
	FILINFO fno;
	FIL *fp;

	stdio_init_all();
	time_init();
	adc_init();

	sleep_ms(2000);

	init_bus();

	SD = sd_get_by_num(0);

	retval = f_mount(&SD->fatfs, SD->pcName, 1);

	if (retval != FR_OK)
	{
		printf("f_mount error: %s (%d)\n", FRESULT_str(retval), retval);
		my_error(FERR_MOUNT);
	}

	retval = f_getcwd(buffer, 1024);

	if (retval != FR_OK)
	{
		printf("f_getcwd error: %s (%d)\n", FRESULT_str(retval), retval);
		my_error(FERR_GCWD);
	}
#ifdef APRIDEBUG
	printf("Current directory is: %s\n", buffer);
#endif
	hd_conf = read_config();

	if (hd_conf == NULL)
	{
		printf("Config: syntax error.\n");
		my_error(FERR_SYNTAX);
		hd_conf->numdrvs = 0;
	}

	for (i = 0; i < hd_conf->numdrvs; i++)
	{
		if (DRV_EXISTS(i))
		{
			filename = hd_conf->drvparams[i].filename;
#ifdef APRIDEBUG
			print_fileinfo(filename);
#endif

			create = 0;

			retval = f_stat(filename, &fno);

			if (retval != FR_OK)
			{
				create = 1;

				fp = (FIL *) malloc(sizeof(FIL));
				retval = f_open(fp, filename, FA_READ|FA_WRITE|FA_OPEN_ALWAYS);

				ptr = create_drvimage(hd_conf->drvparams[i].type, &size);

				f_write(fp, ptr, 512, &written);

				for (j = 0; j < 512; j++)
					buffer[i] = 0xff;

				for (j = 512; j < size; j += 512)
					f_write(fp, buffer, 512, &written);

				f_close(fp);
			}
		}
	}

#ifdef APRIDEBUG
	printf("About to launch main loops.\n");
#endif

	multicore_launch_core1(host_interface);

	wd_command_interpreter();
}

void my_panic(int errorcode)
{
	int i, j;

	for (i = 0; i < 3; i++)
	{
		blink_led_short();

		sleep_ms(100);
	}

	sleep_ms(1000);

	j = flashcodes[errorcode][0];
	j++;
	
	while(1)
	{
		for (i = 1; i < j; i++)
		{
			if (flashcodes[errorcode][i] == 0)
				blink_led_short();
			else
				blink_led_long();

			sleep_ms(500);
		}

		sleep_ms(1000);
	}
}

void my_error(int errorcode)
{
	int i, j, k;

	for (i = 0; i < 3; i++)
	{
		blink_led_short();

		sleep_ms(100);
	}

	sleep_ms(1000);

	j = flashcodes[errorcode][0];
	j++;
	
	for (k = 0; k < 3; k++)
	{
		for (i = 1; i < j; i++)
		{
			if (flashcodes[errorcode][i] == 0)
				blink_led_short();
			else
				blink_led_long();

			sleep_ms(500);
		}

		sleep_ms(1000);
	}
}

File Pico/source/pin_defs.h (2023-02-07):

#define PIN_D0 0
#define PIN_D1 1
#define PIN_D2 2
#define PIN_D3 3
#define PIN_D4 4
#define PIN_D5 5
#define PIN_D6 6
#define PIN_D7 7

#define PIN_SELECTED 14
#define PIN_READ_WRITE 15

#define PIN_A1 18
#define PIN_A2 19
#define PIN_A3 20
#define PIN_A4 21
#define PIN_A8 22

#define PIN_IOWAIT 28
#define PIN_INT2 27

#define PIN_LED 25

#define BUS_GPIO_MASK	0b0000000000000000000000011111111
#define CTRL_GPIO_MASK	0b0000000000000000110000000000000
#define ADDR_GPIO_MASK	0b0000000001111100000000000000000
#define OUT_GPIO_MASK	0b0001100000000000000000000000000

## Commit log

2023-02-07 First import. Working system but Gerber files are for original design which needs bodging
    [Apricot-Hard-Disk-Interface-B_Cu.gbr, Apricot-Hard-Disk-Interface-B_Mask.gbr, Apricot-Hard-Disk-Interface-B_Paste.gbr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]
2023-02-07 Updated the PCB to the latest schematic and routed the PCB. Added Readme.md files
    [Apricot-Hard-Disk-Interface-B_Cu.gbr, Apricot-Hard-Disk-Interface-B_Mask.gbr, Apricot-Hard-Disk-Interface-B_Paste.gbr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]
2023-02-07 Deleted old and unused KiCAD schematic files from the false start of the project.
    [Apricot-Hard-Disk-Interface.sch, Data-Buffer.kicad_sch, Data-Buffer.sch]
2023-02-08 Updated the Pico source Readme.md file.
2023-03-26 Replaced/Added separate hard disk images for F Series and Portable
    [config.txt]

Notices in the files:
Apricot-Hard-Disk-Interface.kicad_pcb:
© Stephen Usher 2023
